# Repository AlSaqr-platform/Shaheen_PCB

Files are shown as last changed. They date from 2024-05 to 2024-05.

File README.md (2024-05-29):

# Shaheen PCB Board
<div style="text-align: center;">
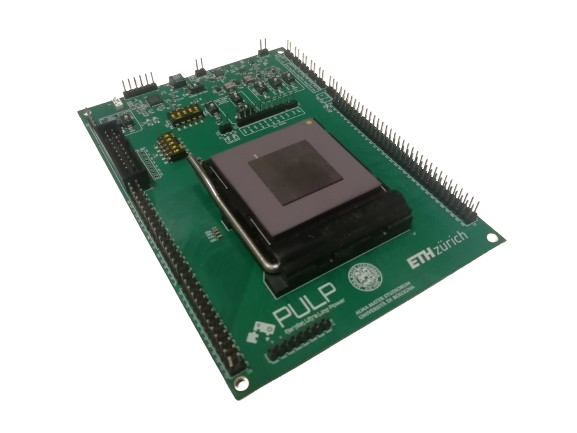
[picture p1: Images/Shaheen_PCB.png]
Shaheen PCB
    
</div>

# Introduction

This repository houses Altium source files and PDF schematics for the Shaheen's PCB design.
The PCB designed for bringing up the Shaheen SoC serves as a versatile platform for initial chip testing and configuration. It provides flexible configuration options and extensive testability features, allowing for comprehensive evaluation and debugging of the Shaheen chip's functionality. This design facilitates the identification and resolution of potential issues, ensuring the chip performs as expected in various scenarios and applications.

This board has been utilized for the power and performance characterization of the Shaheen SoC.

We have designed this PCB to the best of our ability and it performed well for us. However we offer no warranty of any kind (see also LICENSE) and provide these as is, without any support.

# Structure of the repository

This repository contains the following folders:

- **`Schematic`**
    - It provides the schematic sheets of Shaheen
        - **`Schematic Sheets`**
            - Individual sheets representing different sections of the overall schematic design, such as power supply, signal routing, and peripheral connections.
        
        - **`Templates and Standards`**
            - Standardized templates and guidelines used to ensure consistency across the schematic documents.

- **`Lib`**
    - This folder contains the design library files

        - **`Component Libraries`**
            - Collections of all the components used in the Shaheen PCB design, each with detailed electrical symbols, parameters, and footprints.

        - **`Integrated Libraries`**
            - Combined libraries that integrate schematic symbols and corresponding PCB footprints for seamless design transfer.

- **`Documentation`**
    - The documentation folder includes PDFs of the schematics, the layout, and a 3D representation of the design.
    It also includes an introduction of the design including an high level block diagram representation and its configuration for bringing up Shaheen SoC.

# License

The Altium designer source files are released under Solderpad v0.51 (`SHL-0.51`) (see `LICENSE`)

# Publications

If you use these PCBs in your work, please cite us:

```
@ARTICLE{10423921,
  author={Valente, Luca and Nadalini, Alessandro and Veeran, Asif Hussain Chiralil and Sinigaglia, Mattia and Sá, Bruno and Wistoff, Nils and Tortorella, Yvan and Benatti, Simone and Psiakis, Rafail and Kulmala, Ari and Mohammad, Baker and Pinto, Sandro and Palossi, Daniele and Benini, Luca and Rossi, Davide},
  journal={IEEE Transactions on Circuits and Systems I: Regular Papers}, 
  title={A Heterogeneous RISC-V Based SoC for Secure Nano-UAV Navigation}, 
  year={2024},
  volume={},
  number={},
  pages={1-14},
  keywords={Standards;Energy efficiency;Drones;Virtual machine monitors;Silicon;Navigation;Internet of Things;Heterogeneous;Linux;low-power;autonomous nano-UAVs;RISC-V},
  doi={10.1109/TCSI.2024.3359044}}

@INPROCEEDINGS {10254698,
author = {L. Valente and A. Veeran and M. Sinigaglia and Y. Tortorella and A. Nadalini and N. Wistoff and B. Sa and A. Garofalo and R. Psiakis and M. Tolba and A. Kulmala and N. Limaye and O. Sinanoglu and S. Pinto and D. Palossi and L. Benini and B. Mohammad and D. Rossi},
booktitle = {2023 IEEE Hot Chips 35 Symposium (HCS)},
title = {Shaheen: An Open, Secure, and Scalable RV64 SoC for Autonomous Nano-UAVs},
year = {2023},
volume = {},
issn = {},
pages = {1-12},
abstract = {Open Source Hardware, the way it should be!},
keywords = {},
doi = {10.1109/HCS59251.2023.10254698},
url = {https://doi.ieeecomputersociety.org/10.1109/HCS59251.2023.10254698},
publisher = {IEEE Computer Society},
address = {Los Alamitos, CA, USA},
month = {aug}
}
```

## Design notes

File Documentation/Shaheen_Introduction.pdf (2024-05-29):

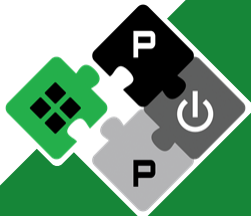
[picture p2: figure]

## pulp-platform.org

## @pulp_platform

## youtube.com/pulp_platform

# PULP Platform Open Source Hardware, the way it should be!

# Energy Efficient Embedded System -(EEES UNIBO)

# Shaheen SoC verification and testing

# Mattia Sinigaglia mattia.sinigaglia5@unibo.it

# Requirements

# - Ubuntu 20.4 Focal Fossa

# - Openocd 11

# - GDB

# - Power Supply – DC 5V 2°

# - Olimex

Add date or a third information here | 2

# Shaheen PCB Block Diagram

# - Input Voltage Regulator chain

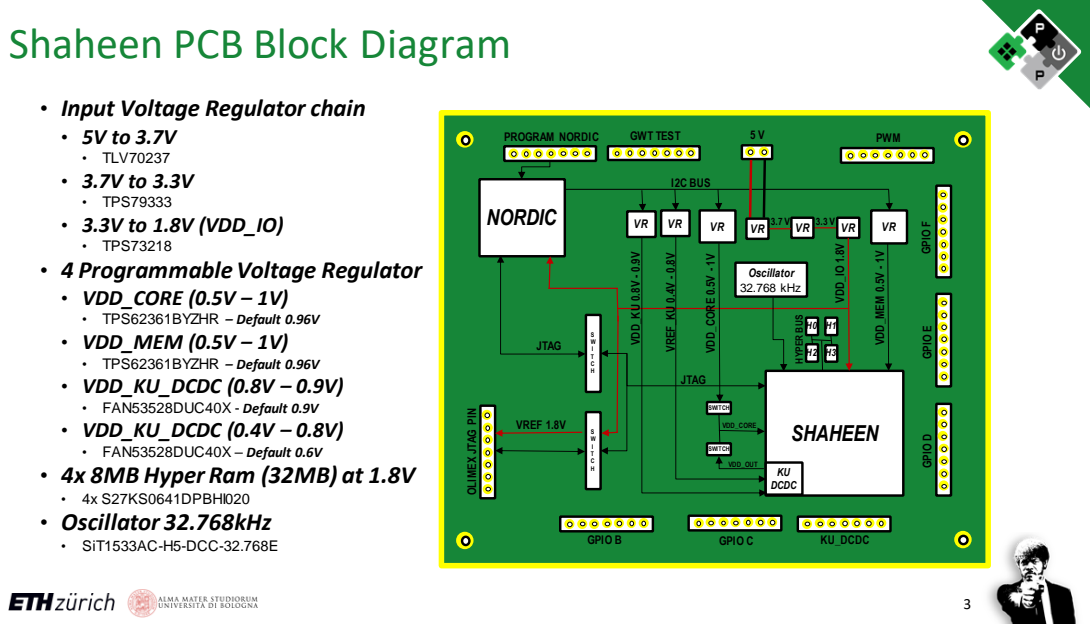
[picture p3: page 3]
• TLV70237 • 3.7V to 3.3V; • TPS79333 • 3.3V to 1.8V (VDD_IO); • TPS73218 • 4 Programmable Voltage Regulator • VDD_CORE (0.5V – 1V); • TPS62361BYZHR – Default 0.96V • VDD_MEM (0.5V – 1V); • TPS62361BYZHR – Default 0.96V • VDD_KU_DCDC (0.8V – 0.9V); • FAN53528DUC40X - Default 0.9V • VDD_KU_DCDC (0.4V – 0.8V); • FAN53528DUC40X – Default 0.6V • 4x 8MB Hyper Ram (32MB) at 1.8V; • 4x S27KS0641DPBHI020 • Oscillator 32.768kHz; • SiT1533AC-H5-DCC-32.768E; NORDIC; SHAHEEN; JTAG; I2C BUS; VDD_IO 1.8V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

GPIO D GPIO E GPIO F

OLIMEX JTAG PIN

# Board Configuration for Bringup

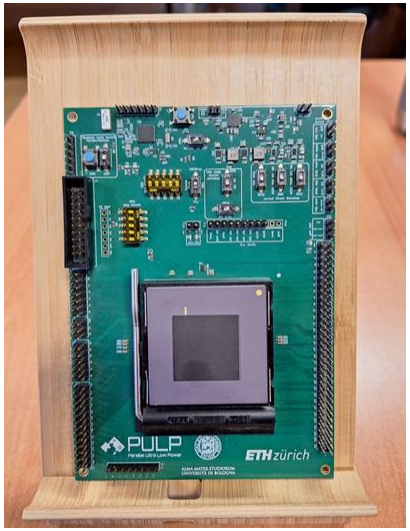
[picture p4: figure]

### - Shaheen Power Switches

- SW9 : VDD CORE (Default 0.96V) - ON
- SW12: VDD MEM (Default 0.96V) - ON
- SW6 : VDD DCDC (Default 0.89V) - OFF
- SW11 : VREF DCDC (Default 0.58V) – OFF
- SW 10 : KUDCDC – OFF

*NB: When OFF the power source can be injected through the power input pins on the

right.

When ON , theese pins can be used to measure the power from the power supply

### - Nordic Power Switch

- SW5: Nordic Power - OFF

### - JTAG Switches

- SW3 : JTAG FROM OLIMEX - ALL ON
- SW2: JTAG FROM NORDIC – ALL OFF
- P5 : this header can be used for debugging purposes

### - Reset

- SW7: reset source OFF (ON – reset generated by NORDIC, OFF – reset from push

button SW8)

### - FLL

- SW4: SoC Clock ON (ON – Clock comes from FLL, OFF – Clock comes from Crystal)

# Nordic jlink programmer connection

### - Jlink programmer

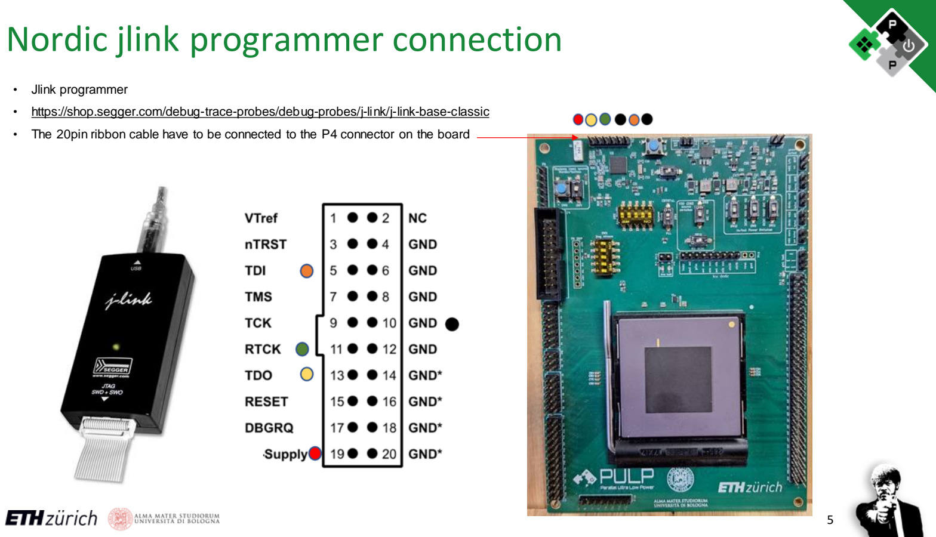
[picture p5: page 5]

### - https://shop.segger.com/debug-trace-probes/debug-probes/j-link/j-link-base-classic

### - The 20pin ribbon cable have to be connected to the P4 connector on the board

Thank you! | Q&A

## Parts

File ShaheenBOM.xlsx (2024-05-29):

Description | Designator | Quantity | Manufacturer 1 | Manufacturer Part Number 1 | Supplier 1 | Supplier Part Number 1 | Supplier 2 | Supplier Part Number 2
Bluetooth antenna | A1 | 1 | Ignion | NN01-102 | Mouser | 128-NN01-102
Multilayer Ceramic Capacitors MLCC - SMD/SMT 100V 0.1uF X7R 0603 10% | C1, C2, C3, C4, C5, C6, C7, C8, C9, C35, C36, C37 | 12 | Kyocera AVX (https://www.mouser.it/manufacturer/kyocera-avx/) | 06031C104KAT2A | Mouser | 581-06031C104KAT2A
Multilayer Ceramic Capacitors MLCC - SMD/SMT 25V 1uF X7R 0603 10% | C10 | 1 | Kyocera AVX (https://www.mouser.it/manufacturer/kyocera-avx/) | 06033C105KAT2A | Mouser | 581-06033C105KAT2A
Multilayer Ceramic Capacitors MLCC - SMD/SMT 50V 0.1uF X7R 0402 10% | C11, C17, C21 | 3 | Kyocera AVX (https://www.mouser.it/manufacturer/kyocera-avx/) | 04025C104KAT4A | Mouser | 581-04025C104KAT4A
Multilayer Ceramic Capacitors MLCC - SMD/SMT 25V 12pF C0G 0402 2% | C12, C13, C15, C16 | 4 | Kyocera AVX (https://www.mouser.it/manufacturer/kyocera-avx/) | 04023U120GAT2A | Mouser | 581-04023U120GAT2A
Multilayer Ceramic Capacitors MLCC - SMD/SMT 10V 4.7uF X5R 0603 10% | C14 | 1 | Kyocera AVX (https://www.mouser.it/manufacturer/kyocera-avx/) | 0603ZD475KAT2A | Mouser | 581-0603ZD475KAT2A
Multilayer Ceramic Capacitors MLCC - SMD/SMT 50V 100pF C0G 0402 5% AEC-Q200 | C18 | 1 | KEMET | C0402C101J5GACAUTO | Mouser | C0402C101J5GAUTO
DO NOT MOUNT | C19 | 1
Multilayer Ceramic Capacitors MLCC - SMD/SMT 50V 0.8pF 0.1pF Tol | C20 | 1 | Kyocera AVX (https://www.mouser.it/manufacturer/kyocera-avx/) | 04025UR80BAT2A | Mouser | 581-04025UR80BAT2A
Multilayer Ceramic Capacitors MLCC - SMD/SMT 0603 50VDC 100pF 5% C0G 0.8mm | C22, C23, C24, C25, C26, C27, C30 | 7 | TDK | C1608C0G1H101J080AA | Mouser | C1608C0G1H101J080AA
Multilayer Ceramic Capacitors MLCC - SMD/SMT 4.7 uF 0603 | C28, C41, C48, C65 | 4 | TDK | C1608X5R1V475M080AC | Mouser | 810-C1608X5R1V475M
Multilayer Ceramic Capacitors MLCC - SMD/SMT 0603 50VDC 100pF 5% C0G 0.8mm | C29, C31, C32, C33 | 4 | TDK | C1608C0G1H101J080AA | Mouser | C1608C0G1H101J080AA
Multilayer Ceramic Capacitors MLCC - SMD/SMT 50V 0.1uF X7R 0603 10% AEC-Q200 | C34 | 1 | KEMET | C0603C104K5RAC3121 | Mouser | 80-C603C104K5RAC3121
Multilayer Ceramic Capacitors MLCC - SMD/SMT 50V 0.1uF X7R 0603 10% AEC-Q200 | C38, C39, C43, C44 | 4 | KEMET | C0603C104K5RAC3121 | Mouser | 80-C603C104K5RAC3121
Multilayer Ceramic Capacitors MLCC - SMD/SMT 0603 6.3VDC 10uF 20% X7T AEC-Q200 EPOXY ONLY | C40, C45 | 2 | TDK | CGA3E1X7T0J106M080AC | Mouser | 810-CGA3E1X7T0J106M0
Multilayer Ceramic Capacitors MLCC - SMD/SMT 0603 (1608M)X5R47F +/-20%6.3V | C42, C46 | 2 | Murata Electronics | GRM188R60J476ME01D | Mouser | 81-GRM188R60J476ME01
Multilayer Ceramic Capacitors MLCC - SMD/SMT 50V 0.1uF X7R 0603 10% AEC-Q200 | C47, C49, C54, C55, C56, C57, C58, C59, C60, C61, C62, C63, C64, C66, C67, C68, C69, C70 | 18 | KEMET | C0603C104K5RAC3121 | Mouser | 80-C603C104K5RAC3121
Multilayer Ceramic Capacitors MLCC - SMD/SMT 0603 4VDC 22uF 20% X6S | C50, C51, C52, C53 | 4 | TDK | C1608X6S0G226M080AC | Mouser | 810-C1608X6S0G226M08
Multilayer Ceramic Capacitors MLCC - SMD/SMT 0603 25VDC 1uF 10% X7R AEC-Q200 | C71 | 1 | Taiyo Yuden (https://eu.mouser.com/manufacturer/taiyo-yuden/) | TMR107B7105KA-T | Mouser | 963-TMR107B7105KA-T
Standard LEDs - SMD Green Water Clr 40mcd 570nm | D1,D2,D6 | 3 | Dialight | 598-8070-107F | Mouser | 645-598-8070-107F
Standard LEDs - SMD WL-SMCW 320mcd 1,9V 0603 S_Red 630nm Adv | D3, D4 | 2 | Wurth Elektronik (https://www.mouser.it/manufacturer/wurth-elektronik/) | 150060SS75003 | Mouser | 710-150060SS75003
Standard LEDs - SMD RED DIFFUSED | D5, D7, D8 | 3 | Dialight | 597-5112-407F | Mouser | 645-597-5112-407F
Headers & Wire Housings 2.54mm CGrid Hdr Shr d /Slt .13AuLF 20Ck | J4A | 1 | Molex | 70246-2004 | Mouser | 538-70246-2004
Multiplexer Switch ICs SPDT 2:1 Mutiplxr 1.65-5.5V; 0.7ohm | IC1 | 1 | Vishay / Siliconix | DG4157EDN-T1-GE4 | Mouser | 78-DG4157EDN-T1-GE4
Switching Voltage Regulators 3A DIGI PROGRAMMABLE TINYBUCK REGULATOR | IC2, IC3 | 2 | onsemi / Fairchild (https://www.mouser.it/manufacturer/fairchild-semiconductor/) | FAN53528DUC40X | Mouser | 512-FAN53528DUC40X
Shaheen 17x17 Socket #17057 (DO NOT MOUNT) | J1 | 1 | Aries Electronics (https://www.mouser.it/manufacturer/aries/)
Headers & Wire Housings WR-PHD 2.54mm THT 64 Pin Dual Pin Headr | J2 | 1 | Wurth Electronics | 61306421121 | Mouser | 710-61306421121
Headers & Wire Housings WR-PHD 2.54mm Hdr 12 P Dual Str Gold | J3 | 1 | Wurth Electronics | 61301221121 | Mouser | 710-61301221121
RF Inductors - SMD 15 NH 5% | L1 | 1 | Murata Electronics | LQW15AN15NJ00D | Mouser | 81-LQW15AN15NJ00D
Power Inductors - SMD 10uH 10% Wound Chip | L2 | 1 | KEMET | L0603B100KDWFT | Mouser | 80-L0603B100KDWFT
RF Inductors - SMD 3.9nH 5 0.84A AEC-Q200 | L3 | 1 | Bourns Inc. | CW105550A-3N9JCT-ND | Mouser | CW105550A-3N9J
Fixed Inductors 2.2uH 20% | L4 | 1 | KEMET | L0603B2R2MPWFT | Mouser | 80-L0603B2R2MPWFT
Shielded Power Inductor, 1 uH, 64 MHz, -40 to 125 degC, 2-Pin SMD, RoHS, Tape and Reel | L5, L6 | 2 | Coilcraft | XFL4020-102MEC | Mouser | 994-XFL4020-102MEC
Shielded Wirewound Inductor 0.33uH 20% 3500mA 0.034Ω 0806 (2016) | L7, L8 | 2 | Murata | DFE201610P-R33M=P2 | Mouser | 81-DFE201610P-R33MP2
THT Vertical Pin Header WR-PHD, Pitch 2.54 mm, Single Row, 2 pins | P1, P2, P5, P6, P7, P8, P10, P17 | 7 | Wurth Electronics | 61300211121 | Mouser | 710-61300211121
THT Vertical Pin Header WR-PHD, Pitch 2.54 mm, Single Row, 6 pins | P3, P4 | 2 | Wurth Electronics | 61300611121 | Mouser | 710-61300611121
THT Vertical Pin Header WR-PHD, Pitch 2.54 mm, Single Row, 7 pins (DO NOT MOUNT) | P6DNP | 1 | Wurth Electronics | 61300711121 | Mouser | 710-61300711121
THT Vertical Pin Header WR-PHD, Pitch 2.54 mm, Single Row, 3 pins | P9 | 1 | Wurth Electronics | 61300311121 | Mouser | 710-61300311121
THT Vertical Pin Header WR-PHD, Pitch 2.54 mm, Single Row, 9 pins | P11 | 1 | Wurth Electronics | 61300911121 | Mouser | 710-61300911121
THT Vertical Pin Header WR-PHD, Pitch 2.54 mm, Single Row, 8 pins | P12 | 1 | Wurth Electronics | 61300811121 | Mouser | 710-61300811121
THT Vertical Pin Header WR-PHD, Pitch 2.54 mm, Dual Row, 26 pins | P13 | 1 | Wurth Electronics | 61302621121 | Mouser | 710-61302621121
THT Vertical Pin Header WR-PHD, Pitch 2.54 mm, Dual Row, 6 pins | P14 | 1 | Wurth Electronics | 61300621121 | Mouser | 710-61300621121
THT Vertical Pin Header WR-PHD, Pitch 2.54 mm, Dual Row, 14 pins | P15 | 1 | Wurth Electronics | 61301421121 | Mouser | 710-61301421121
Thin Film Resistors - SMD CPF 0402 100R 0.1% 25PPM 5K RL | R12, R17, R18, R25, R13, R14 | 6 | TE Connectivity / Holsworthy (https://www.mouser.it/manufacturer/te-holsworthy/) | CPF0402B100RE | Mouser | 279-CPF0402B100RE
Thin Film Resistors - SMD RA73F 1J 1K0 0.1% 1K RL | R1, R2, R3, R4, R7, R8, R9, R10, R11, R19, R21 | 11 | TE Connectivity / Holsworthy (https://www.mouser.it/manufacturer/te-holsworthy/) | RA73F1J1K0BTDF | Mouser | 279-RA73F1J1K0BTDF
Thin Film Resistors - SMD RA73F 1J 10K 0.1% 1K RL | R5, R6 | 2 | TE Connectivity / Holsworthy (https://www.mouser.it/manufacturer/te-holsworthy/) | RA73F1J10KBTDF | Mouser | 279-RA73F1J10KBTDF
Thin Film Resistors - SMD RA73F 1J 1K0 0.1% 1K RL | R22, R23, XX1 | 4 | TE Connectivity / Holsworthy (https://www.mouser.it/manufacturer/te-holsworthy/) | RA73F1J1K0BTDF | Mouser | 279-RA73F1J1K0BTDF
Resistor | R24 | 1 | TE Connectivity / Holsworthy (https://www.mouser.it/manufacturer/te-holsworthy/) | RN73C1J100KBTDF | Mouser | 279-RN73C1J100KBTDF
SWITCH TACTILE SPST-NO 0.05A 12V | SW1, SW8 | 2 | ITT C&K | PTS645SM43SMTR92LFS | Mouser | 611-PTS645SM43SMTR92
WS-DISV 2.54 mm small compact SMD Dip Switch with top tape | SW2, SW3 | 2 | Wurth Electronics | 418121160805 | Digi-Key | 732-6958-1-ND
SWITCH SLIDE DIP SPST 25MA 24V | SW4, SW5, SW7, SW9, SW10, SW6, SW11, SW12 | 8 | Omron | A6S-1104-H | Mouser | 653-A6S1104H
DRAM HyperRAM 1.8-V 64Mb | U1, U6, U7, U8 | 4 | Infineon / Cypress (https://www.mouser.it/manufacturer/infineon/) | S27KS0641DPBHI020 | Mouser | 727-S27KS0641DPBHI02
nRF52832-QFAA-T Multi-protocol Bluetooth Low Energy, ANT and 2.4GHz proprietary system-on-chip | U2 | 1 | Nordic | NRF52832-QFAA-T | Digi-Key | 1490-1068-ND | RS | 169-7008
Linear Regulator | U3 | 1 | Texas Instruments (https://www.mouser.it/manufacturer/texas-instruments/) | TLV70237DBVR | Mouser | 595-TLV70237DBVR
Regulator | U4 | 1 | Texas Instruments (https://www.mouser.it/manufacturer/texas-instruments/) | TPS79333DBVR | Mouser | 595-TPS79333DBVR
2 A, Low VIN, Low Dropout Linear Regulator, 1.6 to 3.6 V Vin, 1.8 V Vout, Industrial, 16-pin QFN (CP-16-3), Reel | U5 | 1 | Analog Devices | ADP1740ACPZ-1.8-R7 | Mouser | 584-ADP1740ACPZ1.8R7
Integrated Circuit | U9, U10 | 2 | Texas Instruments (https://www.mouser.it/manufacturer/texas-instruments/) | TPS62361BYZHR | Mouser | 595-TPS62361BYZHR
XTAL SMD 2016, 32MHz, Cl=8pF, Total Tol: ±40ppm | X1 | 1 | EPSON | FA-128 32.0000MF10Z-AJ3-ND | Digi-Key | SER4233CT-ND
XTAL SMD 3215, 32.768kHz, Cl=9pF, Total Tol: ±50ppm | X2 | 1 | ABRACON (https://www.mouser.it/manufacturer/abracon/) | ABS07-32.768KHZ-9-1-T | Mouser | 815-ABS07-32.7K9-1-T
DO NOT MOUNT | XX2, XX3 | 2
MEMS OSC XO 32.7680KHZ LVCMOS | Y1 | 1 | SiTime | SIT1533AC-H5-DCC-32.768E | Mouser | 788-1533ACH5DCC32.7E
